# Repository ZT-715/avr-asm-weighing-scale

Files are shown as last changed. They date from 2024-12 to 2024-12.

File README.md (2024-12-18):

### AVR Microcontroller-Based Load Cell System

#### Project Overview and Highlights
This project demonstrates a microcontroller-based digital weighing system using an **ATMEGA328P**, developed entirely in **AVR-ASM**. The system features two custom-designed PCBs:
- ATMEGA328p devboard: 20x4 LCD, 3 buttons to show information in kilograms, pounds, and use the tare function, A/D AVcc filter, and an ICSP (In-Circuit Serial Programming).
- High-gain instrumental amplifier: allows weight measurement down to 5 kg ± 5g with a 30 Kg weight cell on the same 7.5V power source as the devboard, with noise filters to maximize A/D range and precision.
- All assembly routines are structured into independent files like timer, ADC, and display control routines.
- Even with TARE, the system shows "OVRW" indicator for overload scenarios.

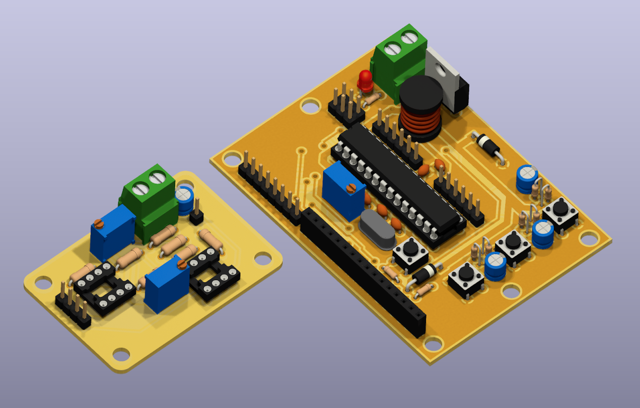
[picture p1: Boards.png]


#### Key Features
1. **Microcontroller and Programming:**
   - Developed using AVRASM2 assembler within MPLab IDE.
   - Programmed with USB-ASP and serial programming connector.
2. **Weight Calibration and Display:**
   - Linear calibration using the TARE button on the devboard and gain adjustments on the amplifier.
   - Precise weight display through precomputed lookup tables for kilograms and pounds.
3. **ADC Integration:**
   - 80%  range of 10-bit ADC of the ATMEGA328P (1-5 volts).
   - Conversion synchronized with Timer 1 for consistent 1 LCD update per
     second.
   - Filtering implemented as per manufacturer instructions on AVcc to reduce noise.
4. **Load Cell Signal Amplification:**
   - Differential output signal amplified with adjustable gain up to 3000 for
     scale adjustment.
   - Offset compensation to overcome amp. op. dead zone around 1V from GND.

#### Results and Next Steps
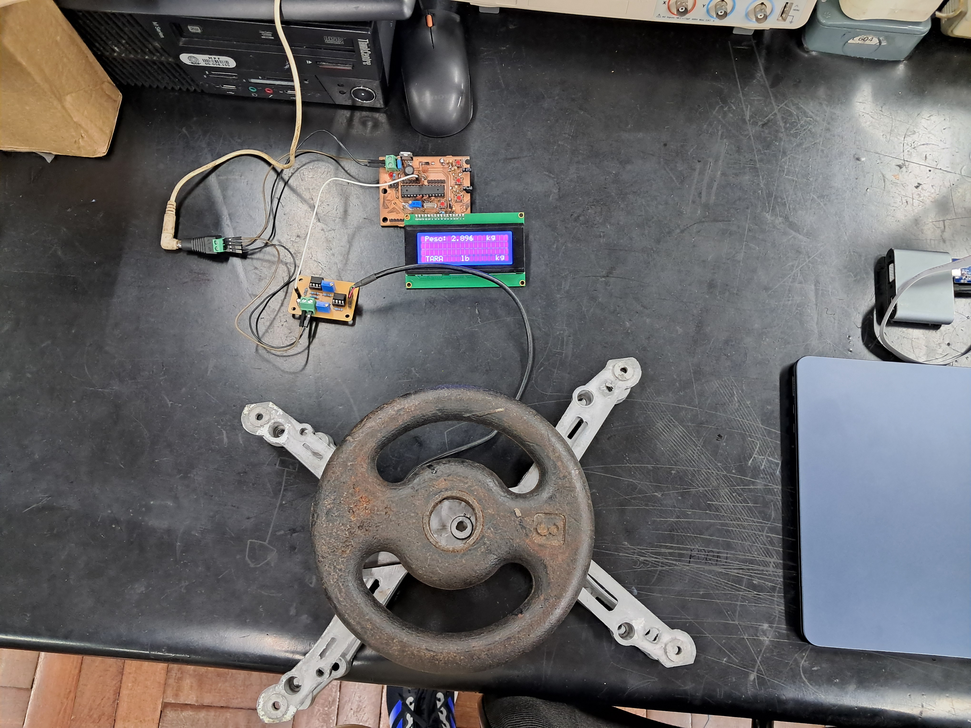
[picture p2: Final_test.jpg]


The system accurately measures weights within the defined range and seamlessly switches between lbs and kgs.
Future improvements include integrating all components into a single PCB, replacing the LCD with a smaller display, and designing a housing for the system. The system may also be battery-powered with efficient use of the ATMEGA328P's sleep states.

#### References
1. [Microchip AVR Microcontroller Hardware Design Considerations](https://ww1.microchip.com/downloads/en/Appnotes/AN2519-AVR-Microcontroller-Hardware-Design-Considerations-00002519B.pdf)
2. [ATMEGA328P Datasheet](https://ww1.microchip.com/downloads/en/DeviceDoc/Atmel-7810-Automotive-Microcontrollers-ATmega328P_Datasheet.pdf)
3. [AVR Instruction Set Manual](https://ww1.microchip.com/downloads/en/DeviceDoc/AVR-InstructionSet-Manual-DS40002198.pdf)
4. [Load Cell Basics](https://en.wikipedia.org/wiki/Load_cell)

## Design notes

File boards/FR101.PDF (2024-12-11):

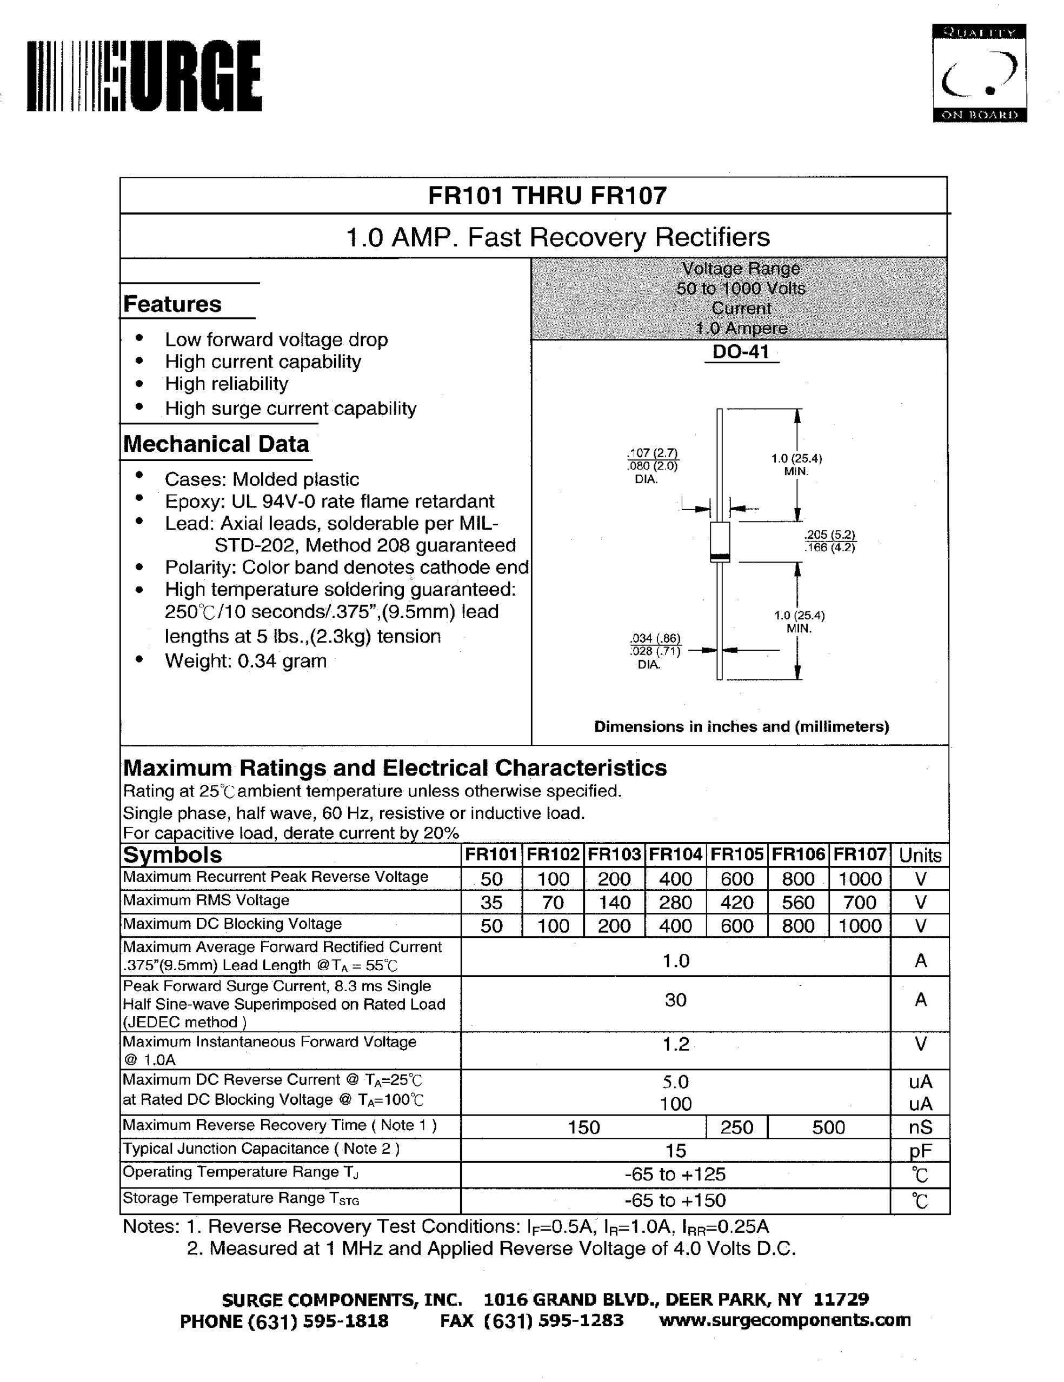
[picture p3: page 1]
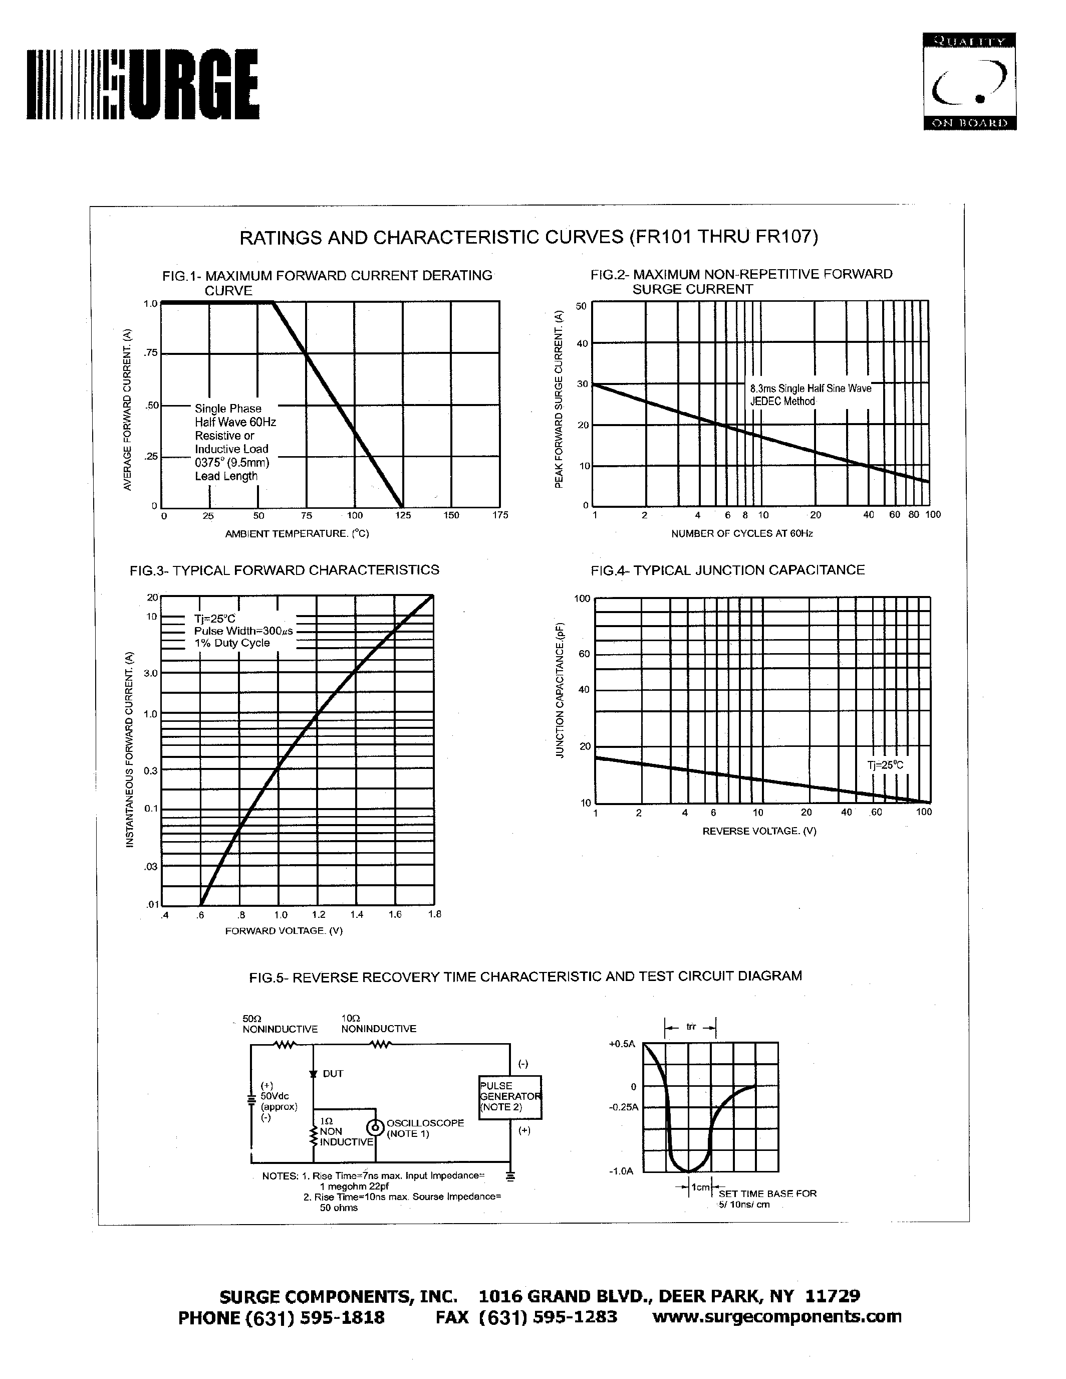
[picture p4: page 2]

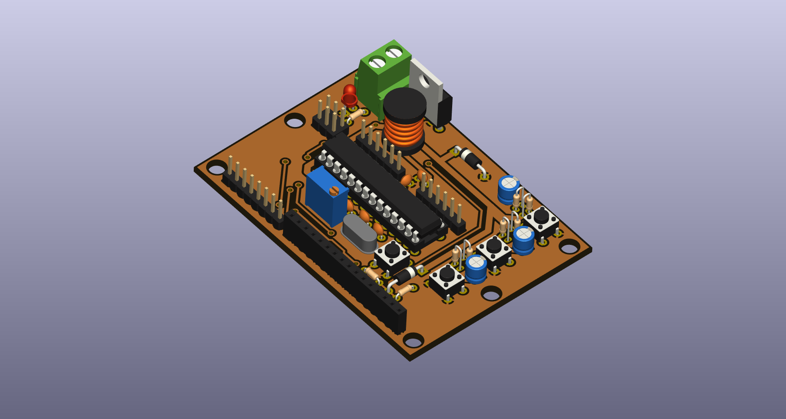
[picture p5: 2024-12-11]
boards/3D v2024.png

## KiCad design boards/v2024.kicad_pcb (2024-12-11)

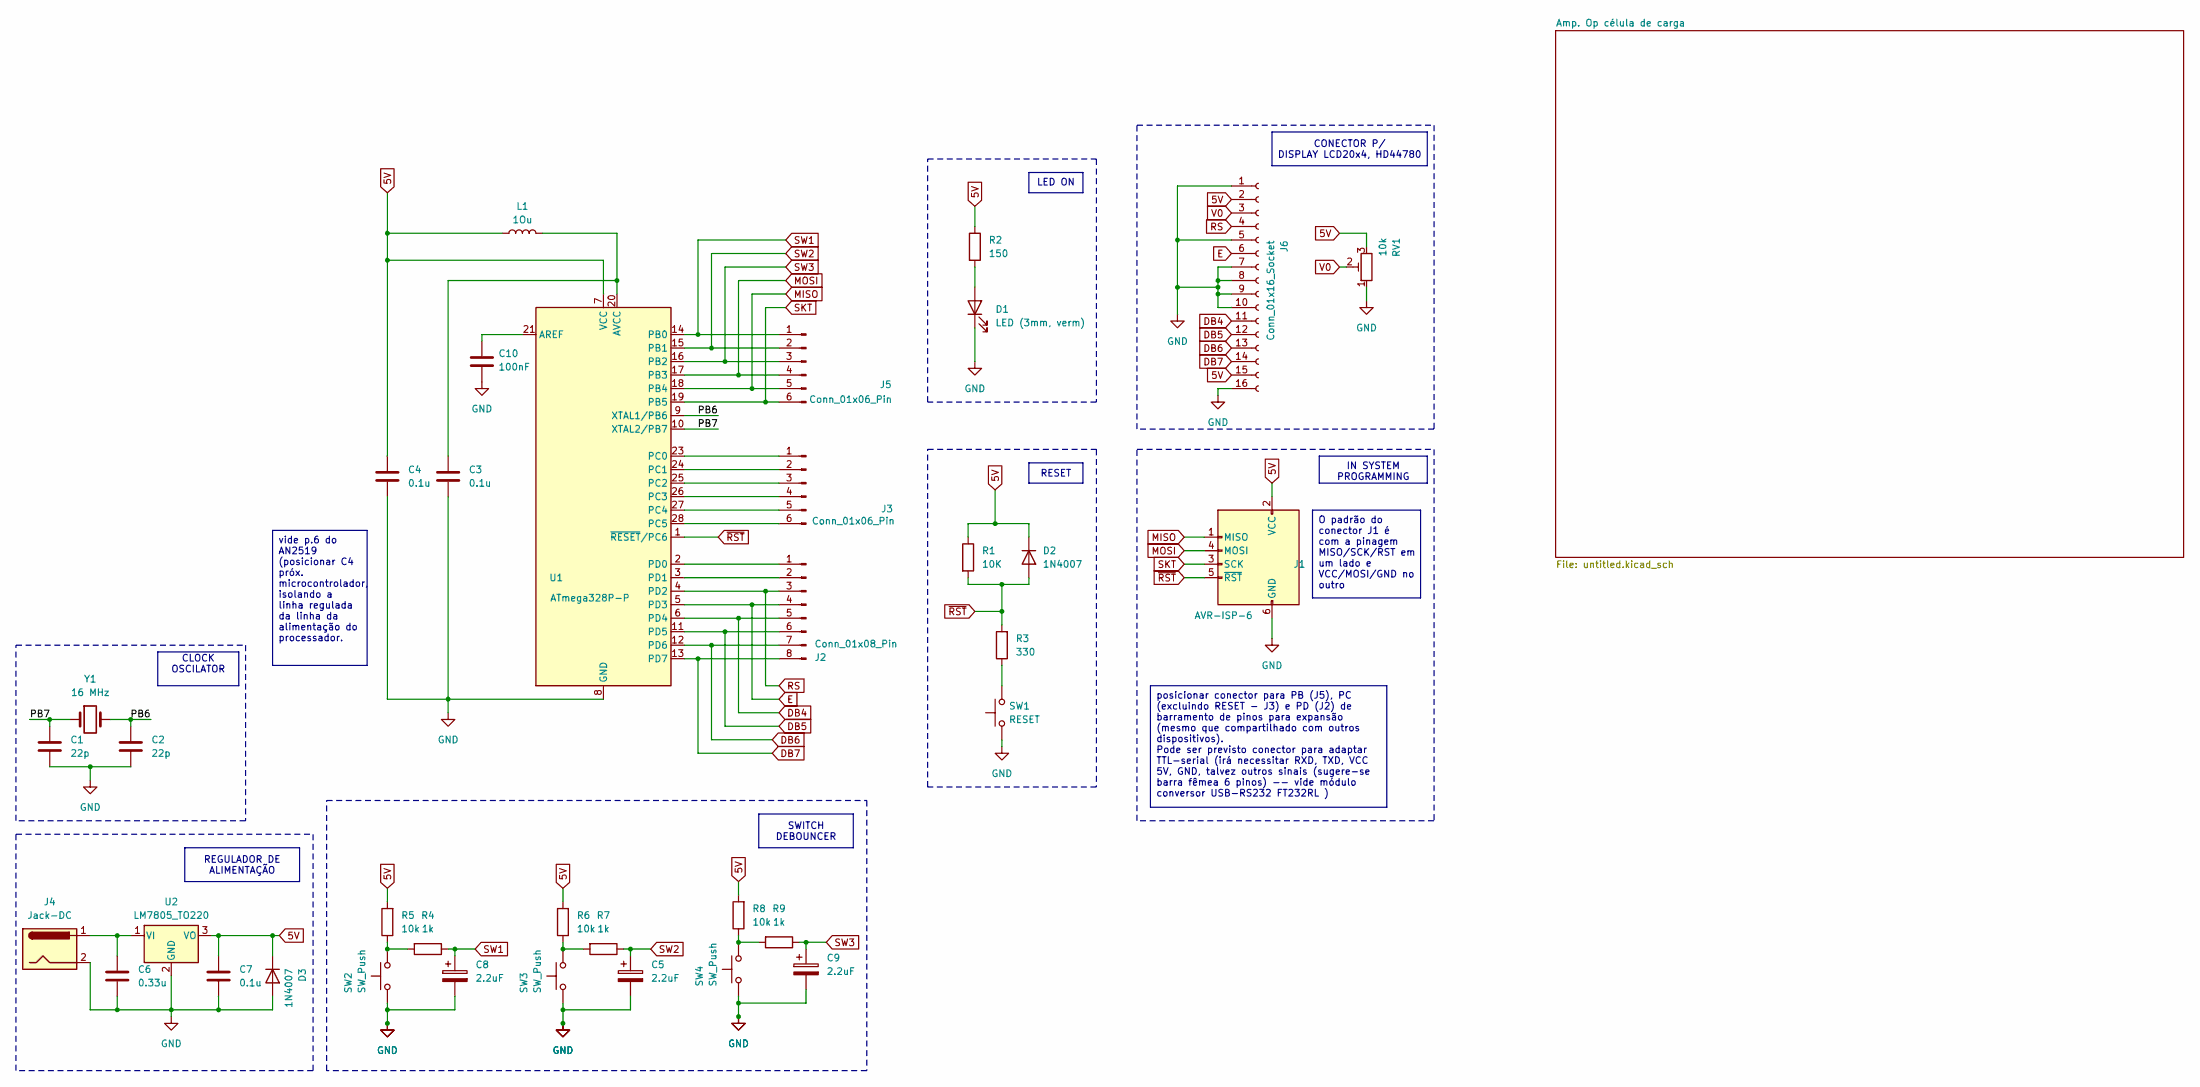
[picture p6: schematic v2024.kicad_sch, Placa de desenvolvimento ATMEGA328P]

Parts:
C1, C2: 22p; C_Disc_D3.4mm_W2.1mm_P2.50mm
C3, C4, C7: 0.1u; C_Disc_D3.4mm_W2.1mm_P2.50mm
C5, C8, C9: 2.2uF; CP_Radial_D5.0mm_P2.00mm
C6: 0.33u; C_Disc_D3.4mm_W2.1mm_P2.50mm
C10: 100nF; C_Disc_D3.4mm_W2.1mm_P2.50mm
D1: LED (3mm, verm); LED_D3.0mm
D2, D3: 1N4007; D_DO-41_SOD81_P10.16mm_Horizontal
J1: AVR-ISP-6; IDC-Header_2x03_P2.54mm_Vertical
J2: Conn_01x08_Pin; PinHeader_1x08_P2.54mm_Vertical
J3, J5: Conn_01x06_Pin; PinHeader_1x06_P2.54mm_Vertical
J4: Jack-DC; TerminalBlock_bornier_kre-2_P5.08mm
J6: Conn_01x16_Socket; PinHeader_1x16_P2.54mm_Vertical
L1: 1Ou; L_Radial_D10.0mm_P5.00mm_Fastron_07M
R1: 10K; R_Axial_DIN0204_L3.6mm_D1.6mm_P5.08mm_Horizontal
R2: 150; R_Axial_DIN0204_L3.6mm_D1.6mm_P5.08mm_Horizontal
R3: 330; R_Axial_DIN0204_L3.6mm_D1.6mm_P5.08mm_Horizontal
R4, R7, R9: 1k; R_Axial_DIN0204_L3.6mm_D1.6mm_P1.90mm_Vertical
R5, R6, R8: 10k; R_Axial_DIN0204_L3.6mm_D1.6mm_P1.90mm_Vertical
RV1: 10k; Potentiometer_Bourns_3296W_Vertical
SW1: RESET; SW_PUSH_6mm_H5mm
SW2, SW3, SW4: SW_Push; SW_PUSH_6mm_H5mm
U1: ATmega328P-P; DIP-28_W7.62mm_w_Socket
U2: LM7805_TO220; TO-220-3_Vertical
Y1: 16 MHz; Crystal_HC49-4H_Vertical

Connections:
5V: C4.1, C7.1, D2.1 (K), D3.1 (K), J1.2 (VCC), J6.2, J6.15, L1.1, R1.1, R2.1, R5.2, R6.2, R8.2, RV1.3, U1.7 (VCC), U2.3 (VO)
/PB6: C2.1, U1.9 (XTAL1/PB6), Y1.2
/PB7: C1.1, U1.10 (XTAL2/PB7), Y1.1
DB4: J2.5, J6.11, U1.6 (PD4)
DB5: J2.6, J6.12, U1.11 (PD5)
DB6: J2.7, J6.13, U1.12 (PD6)
DB7: J2.8, J6.14, U1.13 (PD7)
E: J2.4, J6.6, U1.5 (PD3)
GND: C1.2, C2.2, C3.2, C4.2, C5.2, C6.2, C7.2, C8.2, C9.2, C10.2, D1.1 (K), D3.2 (A), J1.6 (GND), J4.2, J6.1, J6.5, J6.7, J6.8, J6.9, J6.10, J6.16, RV1.1, SW1.1, SW2.1, SW3.1, SW4.1, U1.8 (GND), U1.22 (GND), U2.2 (GND); also elsewhere on the board
MISO: J1.1 (MISO), J5.5, U1.18 (PB4)
MOSI: J1.4 (MOSI), J5.4, U1.17 (PB3)
unnamed: D1.2 (A), R2.2
unnamed: J2.1, U1.2 (PD0)
unnamed: J2.2, U1.3 (PD1)
unnamed: J3.1, U1.23 (PC0)
unnamed: J3.2, U1.24 (PC1)
unnamed: J3.3, U1.25 (PC2)
unnamed: J3.4, U1.26 (PC3)
unnamed: J3.5, U1.27 (PC4)
unnamed: J3.6, U1.28 (PC5)
unnamed: R3.1, SW1.2
unnamed: R4.2, R5.1, SW2.2
unnamed: R6.1, R7.2, SW3.2
unnamed: R8.1, R9.2, SW4.2
unnamed: C10.1, U1.21 (AREF)
unnamed: C3.1, L1.2, U1.20 (AVCC)
unnamed: C6.1, J4.1, U2.1 (VI)
RS: J2.3, J6.4, U1.4 (PD2)
SKT: J1.3 (SCK), J5.6, U1.19 (PB5)
SW1: C8.1, J5.1, R4.1, U1.14 (PB0)
SW2: C5.1, J5.2, R7.1, U1.15 (PB1)
SW3: C9.1, J5.3, R9.1, U1.16 (PB2)
V0: J6.3, RV1.2
~RST: D2.2 (A), J1.5 (~RST), R1.2, R3.2, U1.1 (~RESET/PC6)

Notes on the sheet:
O padrão do conector J1 é com a pinagem MISO/SCK/RST em um lado e VCC/MOSI/GND no outro
CLOCK OSCILATOR
IN SYSTEM PROGRAMMING
posicionar conector para PB (J5), PC (excluindo RESET - J3) e PD (J2) de barramento de pinos para expansão (mesmo que compartilhado com outros dispositivos). Pode ser previsto conector para adaptar TTL-serial (irá necessitar RXD, TXD, VCC 5V, GND, talvez outros sinais (sugere-se barra fêmea 6 pinos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
LED ON
RESET
vide p.6 do AN2519 (posicionar C4 próx. microcontrolador, isolando a linha regulada da linha da alimentação do processador.
REGULADOR DE ALIMENTAÇÃO
CONECTOR P/ DISPLAY LCD20x4, HD44780
SWITCH DEBOUNCER

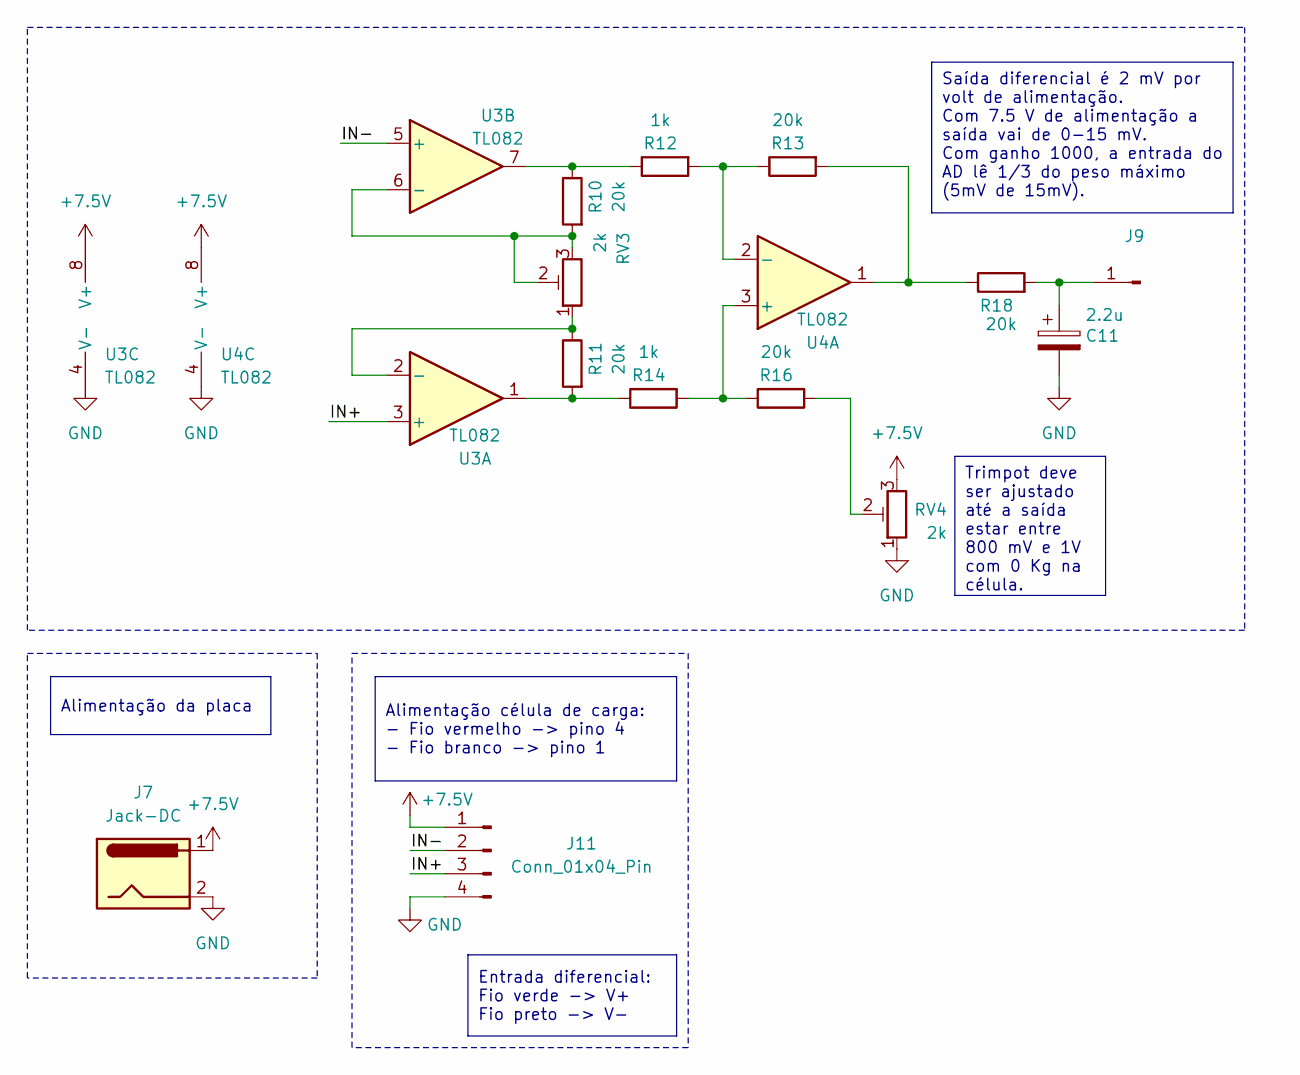
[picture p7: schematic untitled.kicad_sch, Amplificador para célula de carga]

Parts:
C11: 2.2u; CP_Radial_D5.0mm_P2.50mm
J7: Jack-DC; TerminalBlock_bornier_kre-2_P5.08mm
J9: wheigh_out 0.0-5.0V; PinHeader_1x01_P2.54mm_Vertical
J11: Conn_01x04_Pin; PinHeader_1x04_P2.54mm_Vertical
R10, R11, R13, R16, R18: 20k; R_Axial_DIN0207_L6.3mm_D2.5mm_P7.62mm_Horizontal
R12, R14: 1k; R_Axial_DIN0207_L6.3mm_D2.5mm_P7.62mm_Horizontal
RV3, RV4: 2k; Potentiometer_Bourns_3296W_Vertical
U3, U4: TL082; DIP-8_W7.62mm_Socket

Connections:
+7.5V: J7.1, J11.1, RV4.3, U3.8 (V+), U4.8 (V+)
/Amp. Op célula de carga/IN+: J11.3, U3.3 (+)
/Amp. Op célula de carga/IN-: J11.2, U3.5 (+)
GND: C11.2, J7.2, J11.4, RV4.1, U3.4 (V-), U4.4 (V-); also elsewhere on the board
unnamed: C11.1, J9.1, R18.2
unnamed: R10.1, R12.1, U3.7
unnamed: R11.2, R14.1, U3.1
unnamed: R13.2, R18.1, U4.1
unnamed: R16.2, RV4.2
unnamed: R11.1, RV3.1, U3.2 (-)
unnamed: R10.2, RV3.2, RV3.3, U3.6 (-)
unnamed: R14.2, R16.1, U4.3 (+)
unnamed: R12.2, R13.1, U4.2 (-)

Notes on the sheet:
Alimentação célula de carga: - Fio vermelho -> pino 4 - Fio branco -> pino 1
Alimentação da placa
Trimpot deve ser ajustado até a saída estar entre 800 mV e 1V com 0 Kg na célula.
Saída diferencial é 2 mV por volt de alimentação. Com 7.5 V de alimentação a saída vai de 0-15 mV. Com ganho 1000, a entrada do AD lê 1/3 do peso máximo (5mV de 15mV).
Entrada diferencial: Fio verde -> V+ Fio preto -> V-

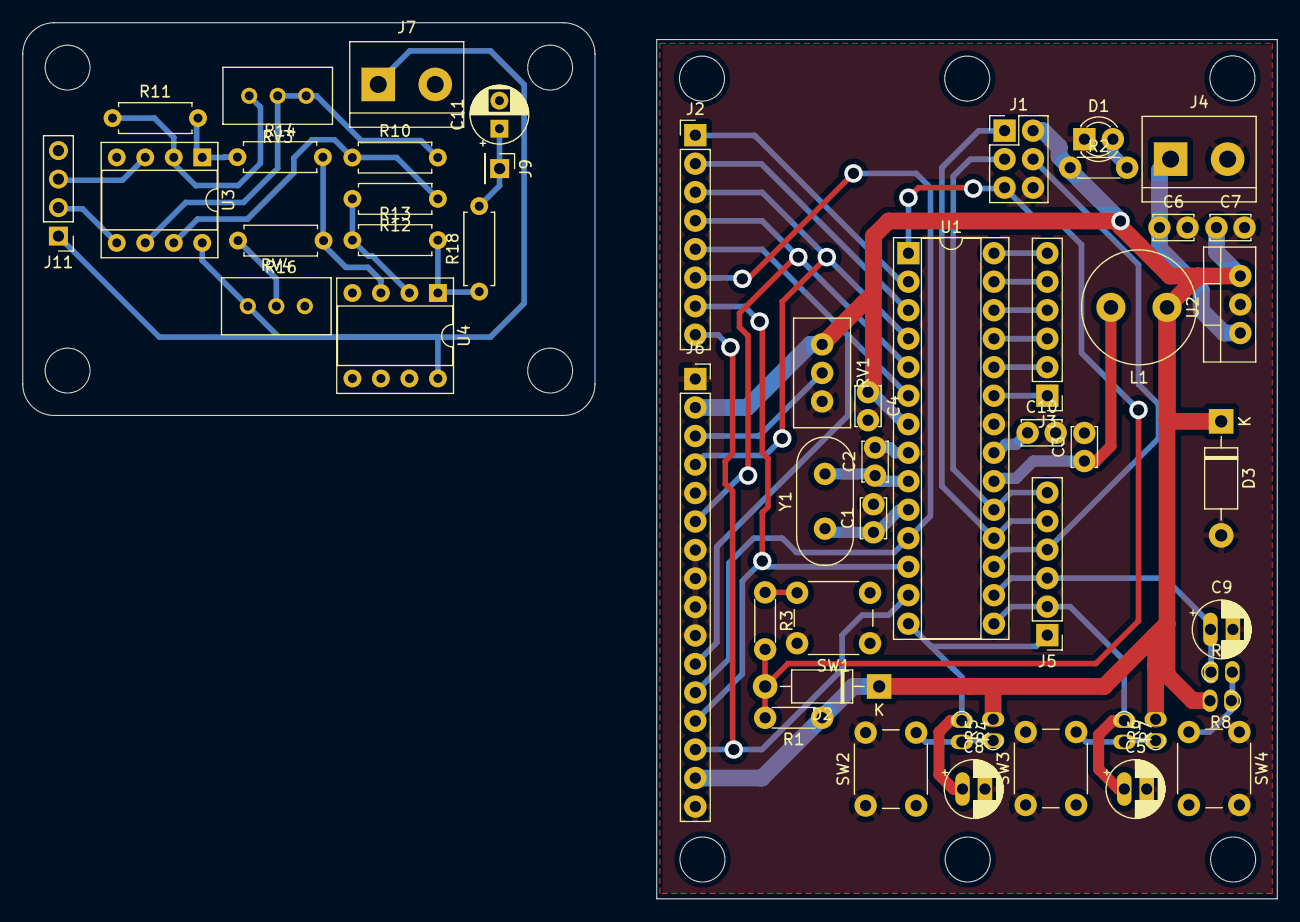
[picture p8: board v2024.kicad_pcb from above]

Board: 2 copper layers, 111.8 x 78.1 mm, 52 parts (0 on the bottom side), 46 nets.

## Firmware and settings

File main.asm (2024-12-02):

.cseg
.org 0x0000                
    jmp init          
.org 0x0006
    jmp switch_isr  ; PCI2 interrupt service routine
.org 0x001A
    jmp TOV1_isr
.org 0x002A
    jmp ADC_isr
.org 0x0034

#include "LUT.asm"
#include "AD_config.asm"
#include "LCD_control.asm"
#include "Switches.asm"
#include "timer.asm"

.def TAREL = r28 
.def TAREH = r29 
.def TARE_SIGN = r24 

init:
;stack_init
    ldi r20, high(RAMEND)
    out SPH, r20
    ldi r20, low(RAMEND)
    out SPL, r20

    call timer1_config
    call switch_config
    call AD_config
    call LCD_init

main:
    ldi row, 2
    ldi column, 0
    clr r15

    clr TAREH
    clr TAREL

    call set_LUT_kg
    
    sei
main_loop:
    cpse switch_toggled, r15
    call LCD_switch_handle

; Weight    
    cpse ad_read_flag, r15
    call update_weight

rjmp main_loop

update_weight:
    cli
    
    ldi r16, 0
    ldi r17, 6
    call LCD_position_cursor

    sbrs ADH, 1
    call AD_tare
    call LCD_write_LUT_weight
    
    mov r16, row
    mov r17, column
    call LCD_position_cursor

    clr ad_read_flag
    
    sei
ret

; dubble_dabble for 10 bits right justfied
; load I/O in r17 (high) and r16 (low)
dubble_dabble:
    push r20
    push r26
    push r27
    clr r26
    clr r27
    ldi r20, 16
    
dd_loop:
        lsl r16
        rol r17
        rol r26
        rol r27
   
        dec r20
        breq dd_end

        movw r19:r18, r27:r26

        dd_nb1:
            andi r18, 0x0F
            cpi r18, 5
            brlo dd_nb2
            adiw r27:r26, 3

        dd_nb2:
            mov r18,r26
            swap r18
            andi r18, 0x0F
            cpi r18, 05
            brlo dd_nb3
            adiw r27:r26, 0x30

        dd_nb3:
            andi r19, 0x0F
            cpi r19, 05
            brlo dd_nb4

            push r20
            ldi r20, 3
            add r27, r20
            pop r20

        dd_nb4:
            mov r19, r27
            swap r19
            andi r19, 0x0F
            cpi r19, 05
            brlo dd_nx
            
            push r20
            ldi r20, 0x30
            add r27, r20
            pop r20
        
        dd_nx:
        rjmp dd_loop

    dd_end:
    movw r17:r16, r27:r26
    pop r27
    pop r26
    pop r20
 ret

; Valores em r17 (high) e r16 (low)
LCD_write_weight:

    push r16
    mov r16, TARE_sign
    call LCD_char
    pop r16

    movw r19:r18, r17:r16

    swap r17
    swap r16

    andi r17, 0x0F ; 1st
    andi r19, 0x0F ; 2nd
    andi r16, 0x0F ; 3rd
    andi r18, 0x0F ; 4th 
    
    ldi r20, '0'
    add r16, r20
    add r17, r20
    add r18, r20
    add r19, r20
    
    push r16

    mov r16, r17
    call LCD_char
    ldi r16, '.'    
    call LCD_char
    mov r16, r19
    call LCD_char
    pop r16
    call LCD_char
    mov r16, r18
    call LCD_char

ret

LCD_write_LUT_weight:
    mov r16, TARE_sign
    call LCD_char
    
    push zl
    push zh
    ldi r16, LUT_str_len ; 2 characters/byte
    
    ; program memory shift
    lsl ADL 
    rol ADH
    
    ; multiply index (ADC) by string lenght (4 bytes)
    mul ADL, r16
    add ZL, r0
    adc ZH, r1
    
    mul ADH, r16
    add ZH, r0
    
    write_LUT_loop:
	lpm r16, Z+
	cpi r16, 0
	brne write_LUT

	pop zh 
        pop zl
	ret

    write_LUT:    
	call LCD_char
	rjmp write_LUT_loop
  
LCD_switch_handle:
    
    in r16, pinb
    andi r16, 0b0000_0111
    cpi r16, 0b0000_0111
    brne end_sh

    sbrc switch_toggled, 2
    call tare
    sbrc switch_toggled, 1
    call set_lb
    sbrc switch_toggled, 0
    call set_kg

    clr switch_toggled
end_sh:
ret
    
set_lb:
    ldi r16, 0
    ldi r17, 15
    call LCD_position_cursor
    
    ldi r16, 'l'
    call LCD_char
    ldi r16, 'b'
    call LCD_char
    call set_LUT_lb
ret
    
set_kg:
    ldi r16, 0
    ldi r17, 15
    call LCD_position_cursor
    
    ldi r16, 'k'
    call LCD_char
    ldi r16, 'g'
    call LCD_char
    call set_LUT_kg
ret
    
tare:
    call AD_read
    movw TAREH:TAREL, r17:r16
ret

AD_tare:
    cp ADL, TAREL
    cpc  ADH, TAREH
    brlo tare_negative

tare_positve:   
    sub ADL, TAREL
    sbc ADH, TAREH
    
    ldi TARE_SIGN, ' '
ret

tare_negative:
    movw r17:r16, TAREH:TAREL
    sub r16, ADL
    sbc r17, ADH
    movw ADH:ADL, r17:r16

    ldi TARE_SIGN, '-'
ret


LCD_select:

;    cpi row, 0
;    breq LED1
;
;    cpi row, 1
;    breq LED2
;
;    cpi row, 2
;    breq LED3

    ret

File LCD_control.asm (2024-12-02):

.def row = r21
.def column = r22

.equ RS = 2
.equ E = 3
.equ PD = PORTD

.equ LIMPAR_LCD = 0b0000_0001
.equ MODO_ENTRADA = 0b0000_0110
.equ DESLIGAR_LCD =  0b0000_1000
.equ LIGAR_LCD = 0b0000_1100
.equ CONFIG_LCD = 0b0010_1000
.equ POSICIONA_CURSOR = 0b1000_0000 ; 1AAA_AAAA
.equ CURSOR_R = 0b0001_0100
.equ CURSOR_L = 0b0001_0000
.equ RETORNA_CURSOR = 0b0000_0010

.equ LINHA_1 = 0x00
.equ LINHA_3 = 0x14
.equ LINHA_2 = 0x40
.equ LINHA_4 = 0x54

.cseg
DISPLAY_TXT: .db " Peso: 000000  kg",0," ",0," ",0," TARA    lb      kg ",0,0

LCD_init:
    ldi r16, 0xFF
    out DDRD, r16

    rcall LCD_conn
    
    rcall delay_1s

    ldi r16, LIGAR_LCD
    rcall LCD_command
    rcall delay_45ms

    ldi r16, LIMPAR_LCD
    rcall LCD_command
    rcall delay_45ms

    ldi zh, high(DISPLAY_TXT << 1)
    ldi zl, low(DISPLAY_TXT << 1)

    ldi row, 0
    ldi column, 0

    screen0:
        mov r16, row
        ldi r17, 0
        rcall LCD_position_cursor

        inc row

    screen0_loop:
        lpm r16, Z+
        cpi r16, 0
	breq screen0_endline

        rcall LCD_char

        rjmp screen0_loop

    screen0_endline:
        lpm r17, Z
        cpse r16, r17 ; se fim de linha duplo
        rjmp screen0
        ret

; r16 recives line 0-3
; r17 receives column 0-20
LCD_position_cursor:
    cpi r16, 0
    breq line_1

    cpi r16, 1
    breq line_2

    cpi r16, 2
    breq line_3

    cpi r16, 3
    breq line_4

line_1:
    ori r17, LINHA_1
    rjmp LCD_pos
line_2:
    ori r17, LINHA_2
    rjmp LCD_pos
line_3:
    ori r17, LINHA_3
    rjmp LCD_pos
line_4:
    ori r17, LINHA_4
    rjmp LCD_pos

; r17 recives position 0-80 (original LCD mapping)
LCD_pos:
    ori r17, POSICIONA_CURSOR
    mov r16, r17
    rcall LCD_command
    ret

LCD_conn:
    rcall delay_45ms
    ldi r16, 0b0011_0000
    rcall LCD_4bits

    rcall delay_5ms

    ldi r16, 0b0011_0000
    rcall LCD_4bits
    rcall delay_500us

    ldi r16, 0b0011_0000
    rcall LCD_4bits
    rcall delay_45us

    ldi r16, CONFIG_LCD
    andi r16, 0b1111_0000
    rcall LCD_4bits
    rcall delay_45us

    ldi r16, CONFIG_LCD
    rcall LCD_command
    rcall delay_45us

    ldi r16, DESLIGAR_LCD
    rcall LCD_command
    rcall delay_45us

    ldi r16, LIMPAR_LCD
    rcall delay_2ms

    ldi r16, MODO_ENTRADA
    rcall LCD_command
    rcall delay_45us
ret

; r16 receives char to be displayed
LCD_char:
    push r20
    mov r20, r16
    andi r16, 0b1111_0000
    sbi PORTD, RS
    rcall LCD_4bits
    mov r16, r20
    swap r16
    andi r16, 0b1111_0000
    rcall LCD_4bits
    cbi PORTD, RS
    pop r20
ret

; r16 loaded with command
LCD_command:
    push r20
    mov r20, r16
    andi r16, 0b1111_0000
    rcall LCD_4bits
    mov r16, r20
    swap r16
    andi r16, 0b1111_0000
    rcall LCD_4bits
    pop r20
ret

;r16 deve possuír os 4 bits a serem anviados em 0b1111_0000
LCD_4bits:
    push r20
    in r20, PIND
    andi r20, 0b0000_1111
    or r16, r20
    out PORTD, r16 
    call delay_45us
    sbi PORTD, E
    call delay_45us
    cbi PORTD, E
    call delay_45us
    pop r20
    ret

delay_45us:
    push r20
    ldi r20, 240
    loop0:
        dec r20
        brne loop0
    pop r20
    ret

delay_500us:
    push r20
    ldi r20, 11
    loop1:
        call delay_45us
        dec r20
        brne loop1
    pop r20
    ret

delay_2ms:
    push r20
    ldi r20, 45
    loop2:
        call delay_45us
        dec r20
        brne loop2
    pop r20
    ret

delay_5ms:
    push r20
    ldi r20, 110
    loop3:
        call delay_45us
        dec r20
        brne loop3
    pop r20
    ret

delay_45ms:
    push r20
    ldi r20, 9
    loop4:
        call delay_5ms
        dec r20
        brne loop4
    pop r20
    ret

delay_1s:
    push r20
    ldi r20, 200
    loop5:
        call delay_5ms
        dec r20
        brne loop5
    pop r20
    ret

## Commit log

2024-11-17 Convert and print AD read to BCD value on LCD
2024-11-21 Switches file
2024-11-26 Change switch handler to return instead of loop
    Now the handler checks the switches, if they are still
    being pressed, then the handler just returns and main
    loop can continue to execute.
2024-11-26 Define weight sample rate with timer and polling
    TODO:
    Implement AD read with interrupts to increase
    sample rate precision, independently of main
    loop routines
2024-11-26 Fix flag clear for sample rate pulling
    [main.asm]
2024-11-26 Add AD interrupt based sampling 16 kHz
2024-11-30 Change ADC to righ justified
2024-12-01 Change sample rate to 15.625 KHz, instead of 244 Hz
2024-12-01 Add switch between lbs and kgs
2024-12-01 Change sample rate to 16Mhz/256/1024 = 61 Hz
2024-12-01 Change sample rate to 61 Hz
2024-12-01 Change sample rate to 1s
2024-12-02 Add safety: 5V in ADC => OVRW on screen
    OVRW is writen independently of TARE
2024-12-11 Add board KiCad design
    [untitled.kicad_sch, v2024.kicad_pcb, v2024.kicad_sch]
2024-12-11 Add images from the boards and final test
2024-12-11 Add images of the boards and final build
